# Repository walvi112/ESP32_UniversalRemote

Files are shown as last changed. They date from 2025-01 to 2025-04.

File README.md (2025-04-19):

# ESP32 Universal Remote  
A universal remote control powered by ESP32.

<p align="center">  
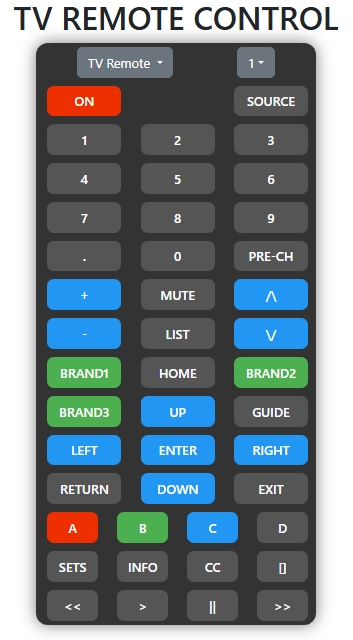
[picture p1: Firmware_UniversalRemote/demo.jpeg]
    
</p>

## Features

### 🔧 Hardware  
- IR receiver for learning new IR codes  
- 7 IR emitters for all-angle transmission

### 💻 Firmware  
- Web server to send/add new IR commands  
- mDNS service broadcasts the web server at [`remote.local`](http://remote.local)  
- Supports up to 5 different TV command sets  
- Supports up to 50 different IR protocols  
- Easy Wi-Fi setup via AP mode

---

## 🚀 Setup

### 📶 Wi-Fi Setup  
1. On startup, press the **user button** to enter AP mode  
2. Connect to the `esp32remote` Wi-Fi network  
3. In your browser, go to [`remote.local`](http://remote.local)  
4. Enter your Wi-Fi information and click `Submit`

<p align="center">  
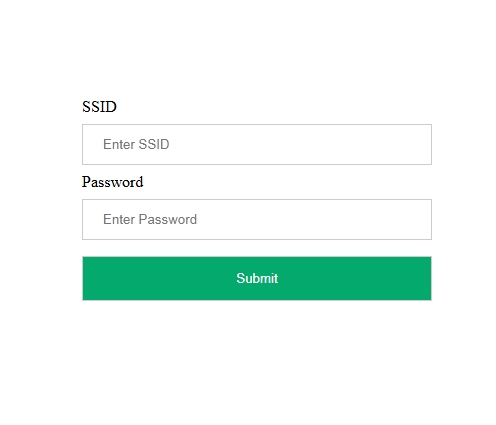
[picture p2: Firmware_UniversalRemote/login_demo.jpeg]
    
</p>

---

### 🔄 Send/Add IR Code

#### ➕ Add IR Code  
1. After setting the Wi-Fi network, go to [`remote.local`](http://remote.local)  
2. Select **Add TV** from the dropdown and choose a remote ID  
3. Click the **Register** button — the LED will start blinking  
4. Point your TV remote at the IR receiver and press a key  
5. If successful, the LED stops blinking; if not, it times out after 5 seconds

<p align="center">  
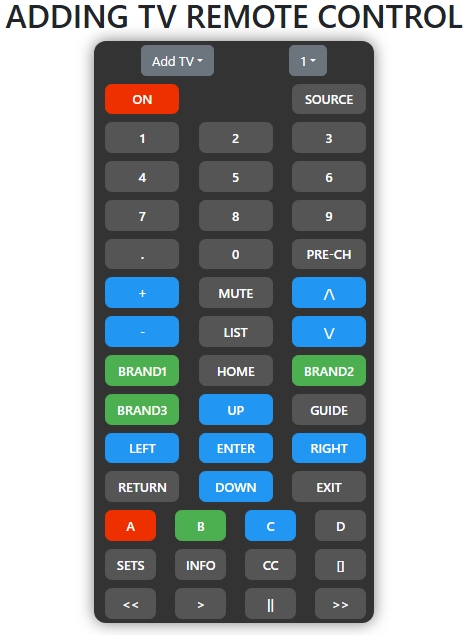
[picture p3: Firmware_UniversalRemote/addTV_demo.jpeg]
    
</p>

#### 📤 Send IR Code  
1. Select **TV Remote** and choose a remote ID from the dropdown  
2. Press the key you want to send

---

### 🐞 Debugging

- Use a serial monitor with **baud rate: 115200** to view logs  
- You can also send serial commands to the device

#### 🔧 Serial Commands  
| Command | Description |
|---|---|
| `led on` | Turn on the LED |
| `led off` | Turn off the LED |
| `send ir _protocol _address _command` | Send IR code (all values in decimal). Refer to `irmpprotocols.h` for `_protocol` values |
| `set wifi _ssid+_pwd` | Set Wi-Fi SSID and password |
| `add tv ir _ir_code _remote_id` | Add new IR command to `_remote_id`. LED will blink while waiting for input |
| `reset wifi` | Enter AP mode (same as pressing user button) |
| `restart` | Restart the device |

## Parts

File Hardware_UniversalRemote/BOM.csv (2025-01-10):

Reference | Value | Datasheet | Footprint | Qty | DNP
C1,C4,C8 | 0.1uF | ~ | Capacitor_THT:C_Disc_D3.4mm_W2.1mm_P2.50mm | 3
C2 | CP/10uF | ~ | Capacitor_THT:CP_Radial_D5.0mm_P2.00mm | 1
C3,C5 | 10uF | ~ | Capacitor_THT:CP_Radial_D4.0mm_P2.00mm | 2
C6 | CP/100uF | ~ | Capacitor_THT:CP_Radial_D8.0mm_P3.50mm | 1
C7 | CP/4.7uF | ~ | Capacitor_THT:CP_Radial_D5.0mm_P2.00mm | 1
C9,C10,C11 | 0.1uF/50V | ~ | Capacitor_THT:C_Disc_D3.4mm_W2.1mm_P2.50mm | 3
CB1 | 750mA/13.5V | ~ | Fuse:Fuse_1812_4532Metric_Pad1.30x3.40mm_HandSolder | 1
D1 | 5.1V/1W | ~ | Diode_THT:D_DO-41_SOD81_P7.62mm_Horizontal | 1
D2 | LED | ~ | LED_THT:LED_D3.0mm | 1
D3,D4,D5,D6,D7,D8,D9 | IR333-A | ~ | LED_THT:LED_D5.0mm | 7
J1 | USB_B_Micro | ~ | Connector_USB:USB_Micro-B_Wuerth_629105150521 | 1
Q1,Q3,Q4,Q5,Q6,Q7 | S8050 | http://www.unisonic.com.tw/datasheet/S8050.pdf | Package_TO_SOT_THT:TO-92_Inline | 6
Q2 | BSS138 | https://www.onsemi.com/pub/Collateral/BSS138-D.PDF | Package_TO_SOT_SMD:SOT-23 | 1
R1,R3,R5,R8,R10,R11,R16 | 10k | ~ | Resistor_THT:R_Axial_DIN0207_L6.3mm_D2.5mm_P7.62mm_Horizontal | 7
R2,R4,R9,R13,R15 | 1k | ~ | Resistor_THT:R_Axial_DIN0207_L6.3mm_D2.5mm_P7.62mm_Horizontal | 5
R6,R7,R12,R14,R17 | 5.6R | ~ | Resistor_THT:R_Axial_DIN0414_L11.9mm_D4.5mm_P15.24mm_Horizontal | 5
SW1,SW2,SW3 | SW_Push | ~ | Button_Switch_THT:SW_TH_Tactile_Omron_B3F-10xx | 3
TP1,TP2,TP3,TP4,TP5 | TestPoint | ~ | TestPoint:TestPoint_Pad_D2.5mm | 5
U1 | ESP32-WROOM-32U | https://www.espressif.com/sites/default/files/documentation/esp32-wroom-32d_esp32-wroom-32u_datasheet_en.pdf | RF_Module:ESP32-WROOM-32U | 1
U2 | LM1117T-3.3 | http://www.ti.com/lit/ds/symlink/lm1117.pdf | Package_TO_SOT_THT:TO-220-3_Horizontal_TabDown | 1
U3 | HS0038B |  | Package_TO_SOT_THT:TO-92_Inline_Wide | 1
U4 | CH340C | https://datasheet.lcsc.com/szlcsc/Jiangsu-Qin-Heng-CH340C_C84681.pdf | Package_SO:SOIC-16_3.9x9.9mm_P1.27mm | 1

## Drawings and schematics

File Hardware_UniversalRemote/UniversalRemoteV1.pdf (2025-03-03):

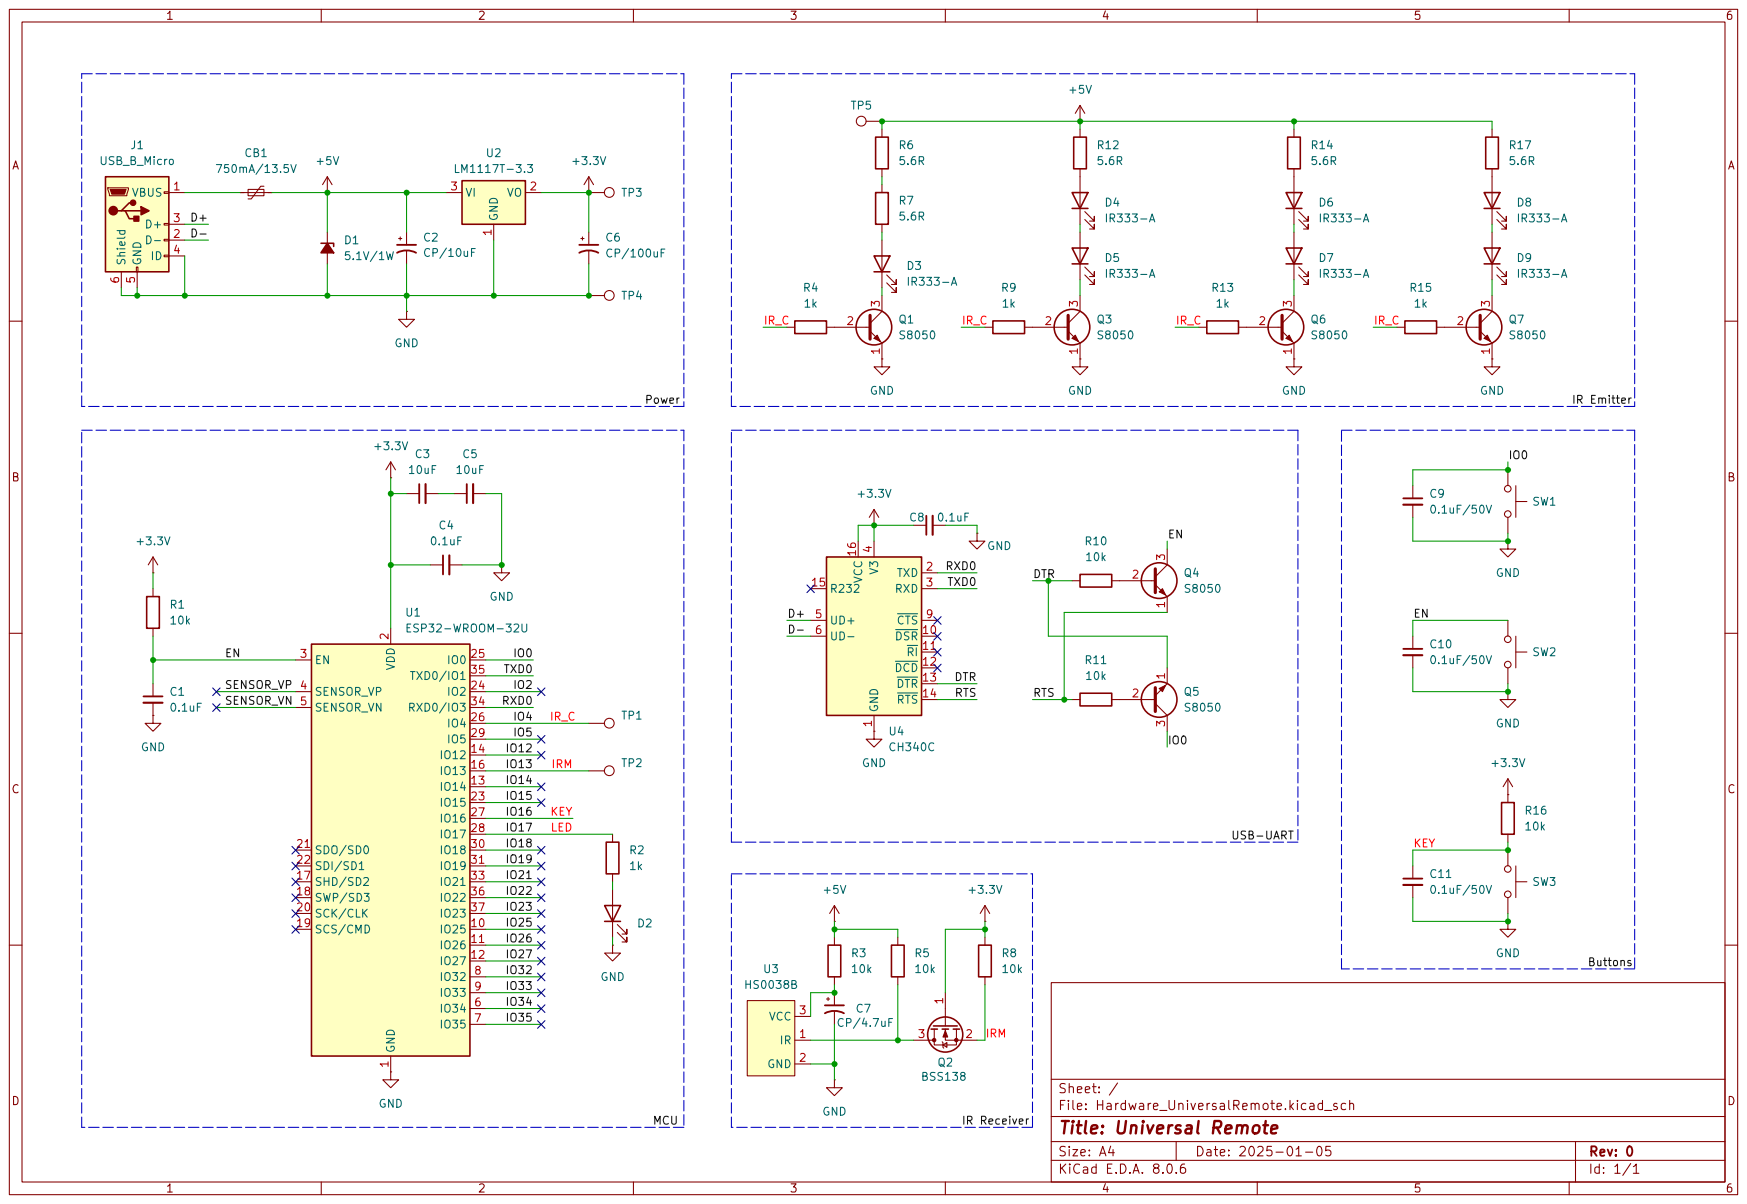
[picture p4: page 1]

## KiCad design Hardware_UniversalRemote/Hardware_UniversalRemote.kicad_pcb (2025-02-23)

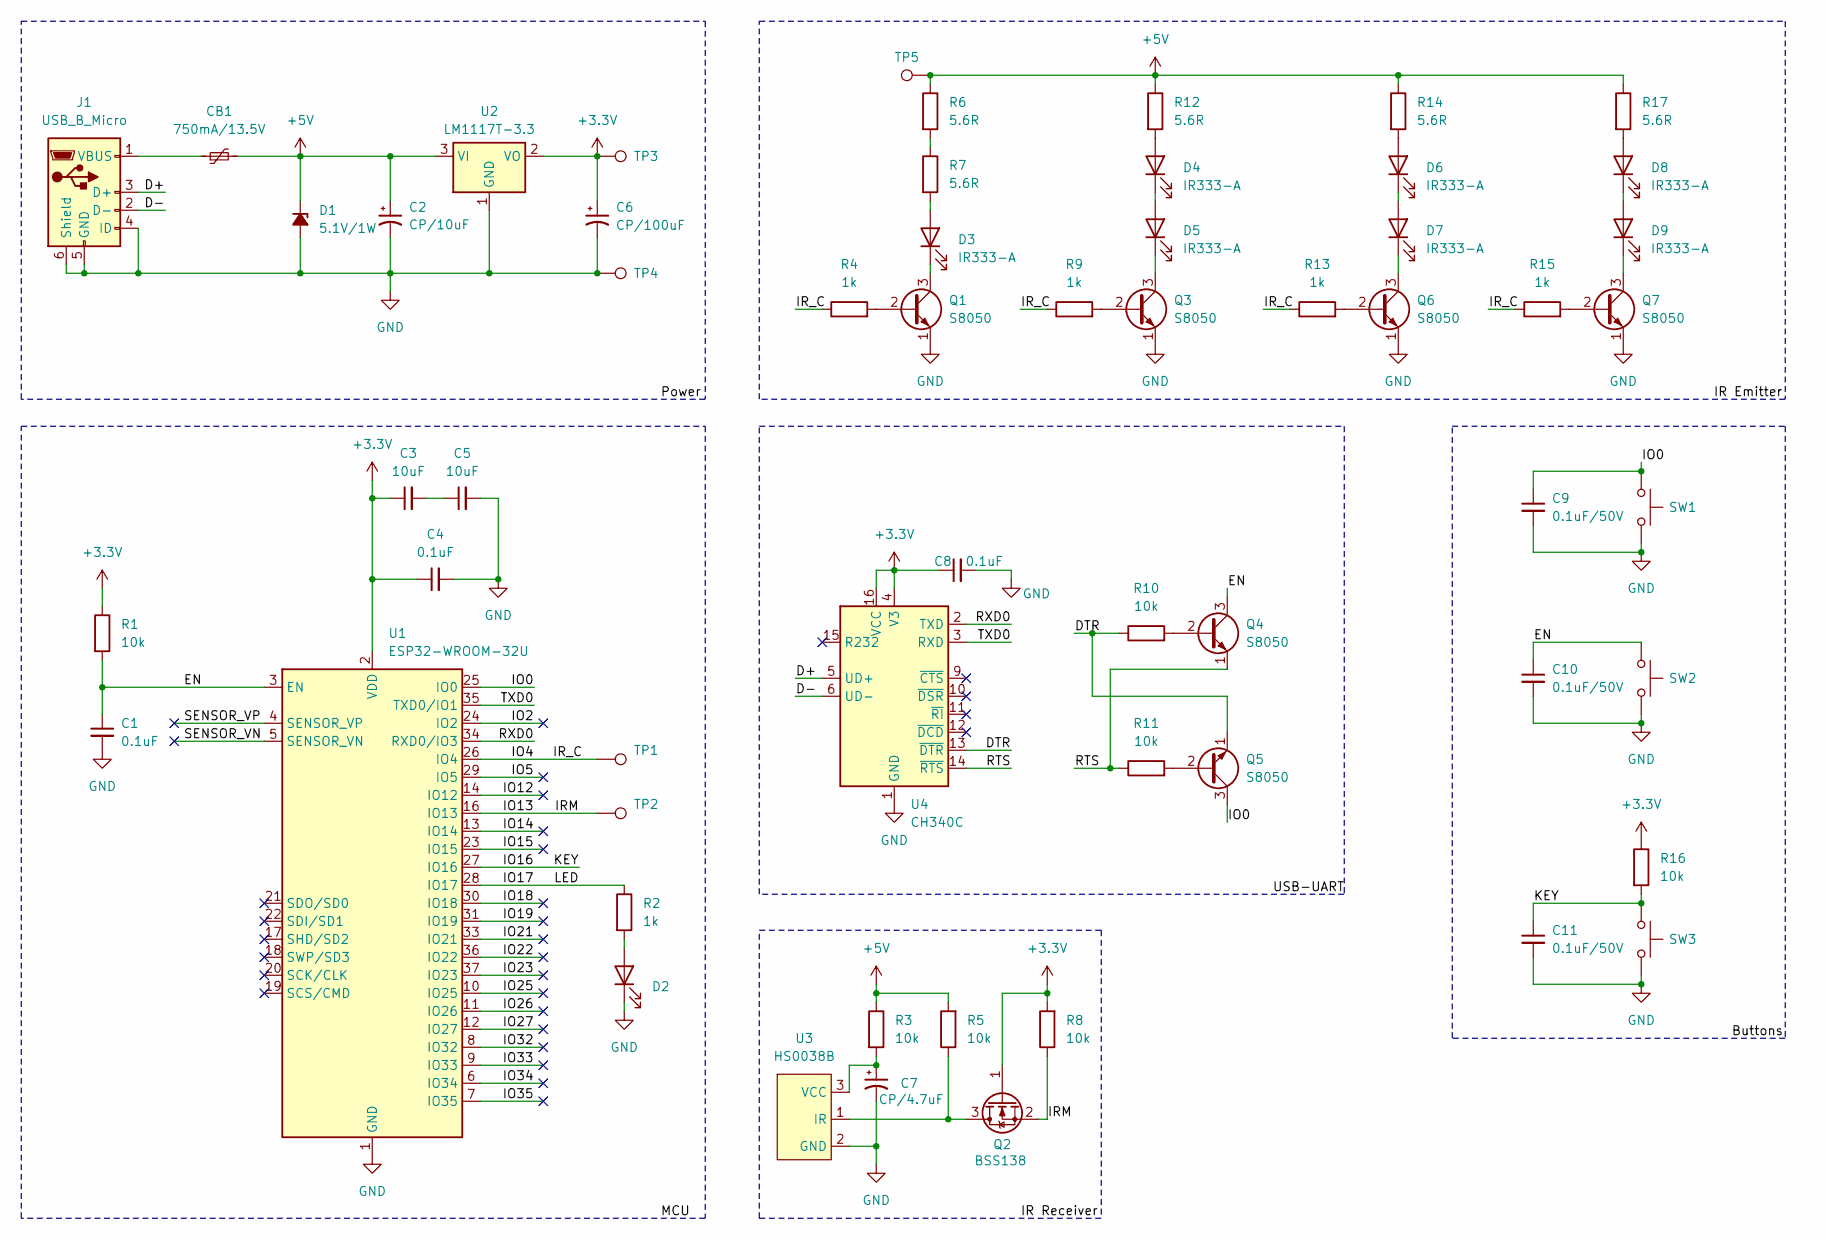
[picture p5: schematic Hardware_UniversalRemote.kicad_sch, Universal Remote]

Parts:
C1, C4, C8: 0.1uF; C_Disc_D3.4mm_W2.1mm_P2.50mm
C2: CP/10uF; CP_Radial_D5.0mm_P2.00mm
C3, C5: 10uF; CP_Radial_D4.0mm_P2.00mm
C6: CP/100uF; CP_Radial_D8.0mm_P3.50mm
C7: CP/4.7uF; CP_Radial_D5.0mm_P2.00mm
C9, C10, C11: 0.1uF/50V; C_Disc_D3.4mm_W2.1mm_P2.50mm
CB1: 750mA/13.5V; Fuse_1812_4532Metric_Pad1.30x3.40mm_HandSolder
D1: 5.1V/1W; D_DO-41_SOD81_P7.62mm_Horizontal
D2: LED; LED_D3.0mm
D3: IR333-A; LED_D5.0mm
D4, D5, D6, D7, D8, D9: IR333-A; LED_D5.0mm_Horizontal_O3.81mm_Z9.0mm
J1: USB_B_Micro; USB_Micro-B_Wuerth_629105150521
Q1, Q3, Q4, Q5, Q6, Q7: S8050; TO-92_Inline
Q2: BSS138; SOT-23
R1, R3, R5, R8, R10, R11, R16: 10k; R_Axial_DIN0207_L6.3mm_D2.5mm_P7.62mm_Horizontal
R2, R4, R9, R13, R15: 1k; R_Axial_DIN0207_L6.3mm_D2.5mm_P7.62mm_Horizontal
R6, R7, R12, R14, R17: 5.6R; R_Axial_DIN0414_L11.9mm_D4.5mm_P15.24mm_Horizontal
SW1, SW2, SW3: SW_Push; SW_TH_Tactile_Omron_B3F-10xx
TP1, TP2, TP3, TP4, TP5: TestPoint; TestPoint_Pad_D2.5mm
U1: ESP32-WROOM-32U
U2: LM1117T-3.3; TO-220-3_Horizontal_TabDown
U3: HS0038B; TO-92_Inline_Wide
U4: CH340C; SOIC-16_3.9x9.9mm_P1.27mm

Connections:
+3.3V: C3.1, C4.1, C6.1, C8.1, Q2.1 (G), R1.1, R8.2, R16.1, TP3.1, U1.2 (VDD), U2.2 (VO), U4.4 (V3), U4.16 (VCC)
+5V: C2.1, CB1.2, D1.1 (K), R3.1, R5.2, R6.1, R12.1, R14.1, R17.1, TP5.1, U2.3 (VI)
/D+: J1.3 (D+), U4.5 (UD+)
/D-: J1.2 (D-), U4.6 (UD-)
/DTR: Q5.1 (E), R10.1, U4.13 (~DTR)
/EN: C1.1, C10.1, Q4.3 (C), R1.2, SW2.1, U1.3 (EN)
/IO0: C9.1, Q5.3 (C), SW1.1, U1.25 (IO0)
/IO2: U1.24 (IO2)
/IO4: R4.1, R9.1, R13.1, R15.1, TP1.1, U1.26 (IO4)
/IO5: U1.29 (IO5)
/IO12: U1.14 (IO12)
/IO13: Q2.2 (S), R8.1, TP2.1, U1.16 (IO13)
/IO14: U1.13 (IO14)
/IO15: U1.23 (IO15)
/IO16: C11.1, R16.2, SW3.1, U1.27 (IO16)
/IO17: R2.1, U1.28 (IO17)
/IO18: U1.30 (IO18)
/IO19: U1.31 (IO19)
/IO21: U1.33 (IO21)
/IO22: U1.36 (IO22)
/IO23: U1.37 (IO23)
/IO25: U1.10 (IO25)
/IO26: U1.11 (IO26)
/IO27: U1.12 (IO27)
/IO32: U1.8 (IO32)
/IO33: U1.9 (IO33)
/IO34: U1.6 (IO34)
/IO35: U1.7 (IO35)
/RTS: Q4.1 (E), R11.1, U4.14 (~RTS)
/RXD0: U1.34 (RXD0/IO3), U4.2 (TXD)
/SENSOR_VN: U1.5 (SENSOR_VN)
/SENSOR_VP: U1.4 (SENSOR_VP)
/TXD0: U1.35 (TXD0/IO1), U4.3 (RXD)
GND: C1.2, C2.2, C4.2, C5.2, C6.2, C7.2, C8.2, C9.2, C10.2, C11.2, D1.2 (A), D2.1 (K), J1.4 (ID), J1.5 (GND), J1.6 (Shield), Q1.1 (E), Q3.1 (E), Q6.1 (E), Q7.1 (E), SW1.2, SW2.2, SW3.2, TP4.1, U1.1 (GND), U1.15 (GND), U1.38 (GND), U1.39 (GND), U2.1 (GND), U3.2 (GND), U4.1 (GND)
unnamed: C3.2, C5.1
unnamed: D2.2 (A), R2.2
unnamed: D3.2 (A), R7.2
unnamed: D3.1 (K), Q1.3 (C)
unnamed: D4.2 (A), R12.2
unnamed: D4.1 (K), D5.2 (A)
unnamed: D5.1 (K), Q3.3 (C)
unnamed: D6.2 (A), R14.2
unnamed: D6.1 (K), D7.2 (A)
unnamed: D7.1 (K), Q6.3 (C)
unnamed: D8.2 (A), R17.2
unnamed: D8.1 (K), D9.2 (A)
unnamed: D9.1 (K), Q7.3 (C)
unnamed: CB1.1, J1.1 (VBUS)
unnamed: Q1.2 (B), R4.2
unnamed: Q2.3 (D), R5.1, U3.1 (IR)
unnamed: Q3.2 (B), R9.2
unnamed: Q4.2 (B), R10.2
unnamed: Q5.2 (B), R11.2
unnamed: Q6.2 (B), R13.2
unnamed: Q7.2 (B), R15.2
unnamed: R6.2, R7.1
unnamed: C7.1, R3.2, U3.3 (VCC)

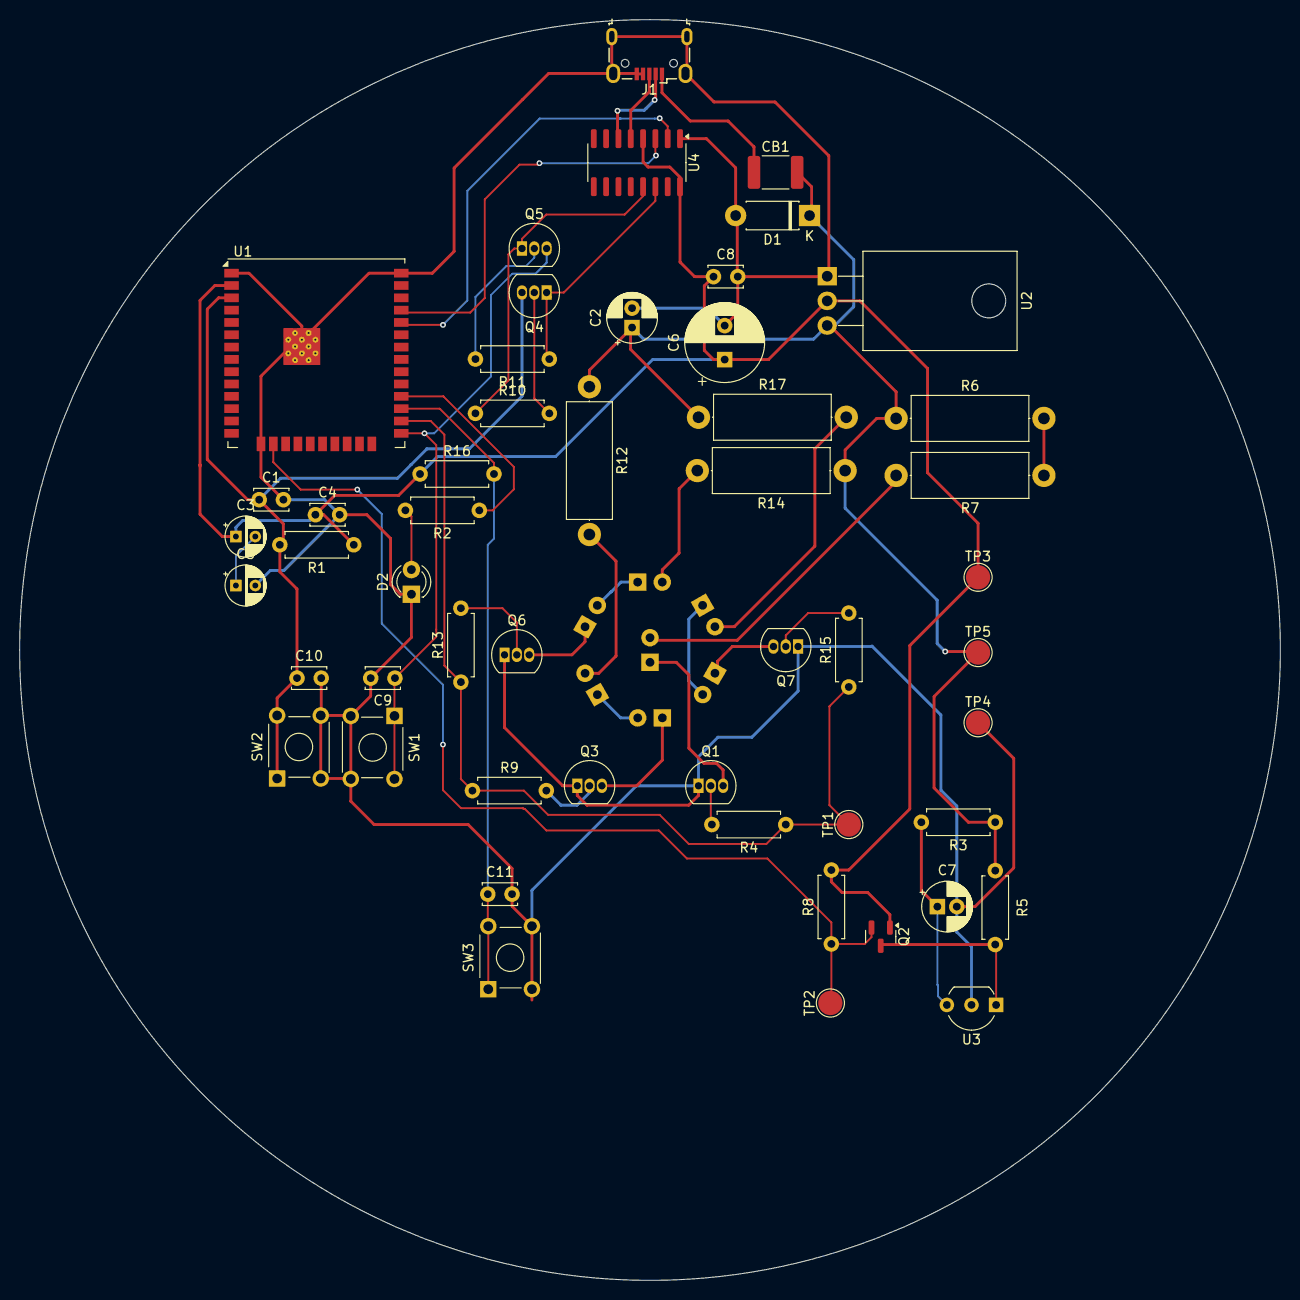
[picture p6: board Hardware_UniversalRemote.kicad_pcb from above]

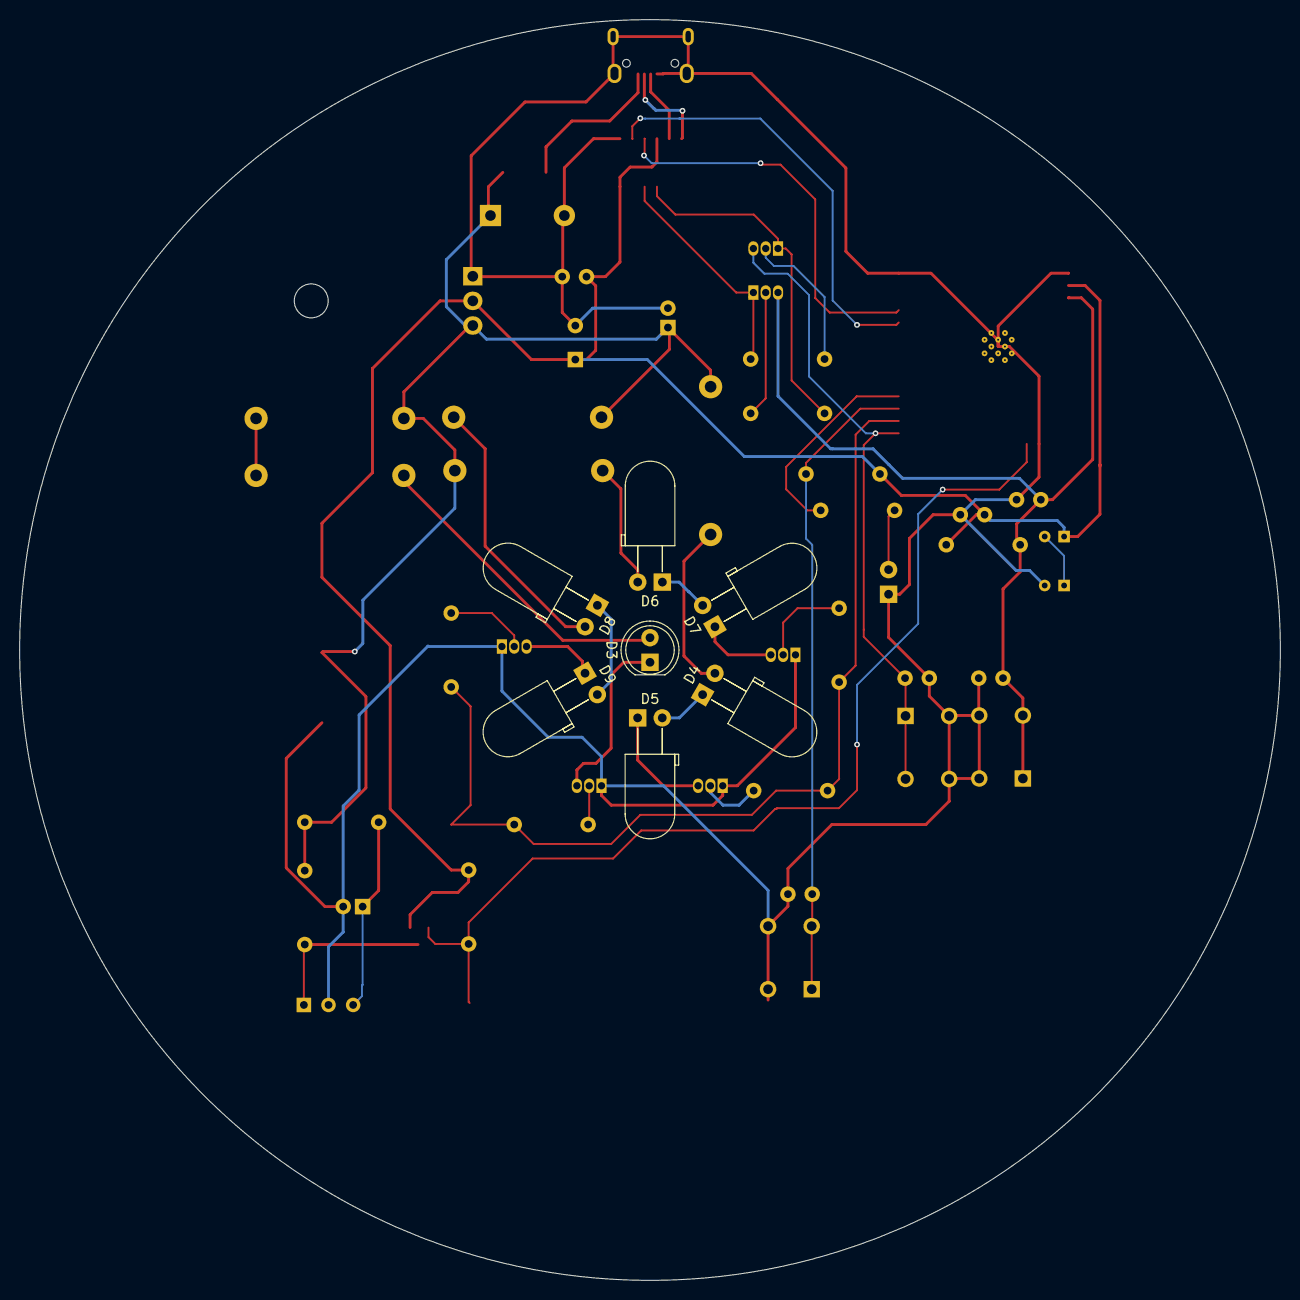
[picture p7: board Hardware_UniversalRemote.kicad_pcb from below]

Board: 2 copper layers, 130.0 x 130.0 mm, 58 parts (7 on the bottom side), 38 nets.

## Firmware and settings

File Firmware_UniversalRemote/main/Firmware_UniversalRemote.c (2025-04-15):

#include <stdio.h>
#include <stdint.h>
#include "freertos/FreeRTOS.h"
#include "freertos/task.h"
#include "driver/gpio.h"
#include "driver/uart.h"
#include "nvs_flash.h"
#include "esp_system.h"
#include "wifi_connect.h"
#include "webserver.h"
#include "ir_manage.h"
#include "pin_config.h"

#define UART_BUFFER_SIZE     2048

TaskHandle_t key_press_task_handle;
char uart_buffer[UART_BUFFER_SIZE];

void cli_task(void *args);
void key_press_task(void *args);

static void IRAM_ATTR key_isr_handler(void *args)
{
    BaseType_t xHigherPriorityTaskWoken;
    vTaskNotifyGiveFromISR(key_press_task_handle, &xHigherPriorityTaskWoken);
    if (xHigherPriorityTaskWoken) {
        portYIELD_FROM_ISR();
    }
}

void app_main(void)
{   
    esp_err_t ret = nvs_flash_init();
    if (ret == ESP_ERR_NVS_NO_FREE_PAGES || ret == ESP_ERR_NVS_NEW_VERSION_FOUND) {
        ESP_ERROR_CHECK(nvs_flash_erase());
        ret = nvs_flash_init();
    }
    ESP_ERROR_CHECK(ret);

    const uart_port_t uart_num = UART_NUM_0;
    uart_config_t uart_config = {
        .baud_rate = 115200,
        .data_bits = UART_DATA_8_BITS,
        .parity = UART_PARITY_DISABLE,
        .stop_bits = UART_STOP_BITS_1,
        .flow_ctrl = UART_HW_FLOWCTRL_DISABLE,
    };
    ESP_ERROR_CHECK(uart_param_config(uart_num, &uart_config));
    ESP_ERROR_CHECK(uart_set_pin(uart_num, GPIO_NUM_1, GPIO_NUM_3, UART_PIN_NO_CHANGE, UART_PIN_NO_CHANGE));
    ESP_ERROR_CHECK(uart_driver_install(uart_num, UART_BUFFER_SIZE, 0, 0, NULL, 0));

    gpio_reset_pin(LED_PIN);
    gpio_set_direction(LED_PIN, GPIO_MODE_OUTPUT);
    gpio_set_level(LED_PIN, 1);

    gpio_reset_pin(KEY_PIN);
    gpio_set_direction(KEY_PIN, GPIO_MODE_INPUT);
    gpio_set_pull_mode(KEY_PIN, GPIO_FLOATING);
    gpio_set_intr_type(KEY_PIN, GPIO_INTR_NEGEDGE);

    gpio_install_isr_service(ESP_INTR_FLAG_IRAM);
    gpio_isr_handler_add(KEY_PIN, key_isr_handler, (void*) KEY_PIN);
    gpio_dump_io_configuration(stdout, (1ULL << LED_PIN) | (1ULL << KEY_PIN));

    ESP_ERROR_CHECK(ir_init());
    ESP_ERROR_CHECK(ir_storage_init());
    ESP_ERROR_CHECK(wifi_init());
    ESP_ERROR_CHECK(startwebserver());

    xTaskCreatePinnedToCore(&cli_task, "CLI_TASK", 4096, NULL, 1, NULL, 1);
    xTaskCreatePinnedToCore(&key_press_task, "KEY_PRESS_TASK", 2048, NULL, 2, &key_press_task_handle, 1);
}

esp_err_t str_to_parram_int(char *input, int *output_array, unsigned int array_length)
{
    uint8_t token_count = 0;
    char *pch = strtok(input, " ");
    while (pch != NULL && token_count < array_length) {
        output_array[token_count] = strtol(pch, NULL, 10);
        pch = strtok(NULL, " ");
        token_count += 1;    
    }
    if (token_count < array_length) {
        return ESP_FAIL;
    }
    return ESP_OK;
}

esp_err_t str_to_parram_str(char *input, char **output_array, unsigned int array_length)
{
    uint8_t token_count = 0;
    char *pch = strtok(input, "+");
    while (pch != NULL && token_count < array_length) {
        printf("%s\n", pch);
        output_array[token_count] = pch;
        pch = strtok(NULL, "+");
        token_count += 1;
    }
    if (token_count < array_length) {
        return ESP_FAIL;
    }
    return ESP_OK;
}

void key_press_task(void *args)
{
    TickType_t now_tick = 0;
    TickType_t previous_tick = 0;
    while (1)
    {
        ulTaskNotifyTake(pdTRUE, portMAX_DELAY);
        now_tick = xTaskGetTickCount();
        if ((now_tick - previous_tick) >= (DEBOUNCE_PERIOD_MS / portTICK_PERIOD_MS)) {
            previous_tick = now_tick;
            printf("User key pressed\n");
            reset_wifi();
        }
    }
}

void cli_task(void *args)
{
    int length = 0;
    while (1)
    {
        length = uart_read_bytes(UART_NUM_0, uart_buffer, UART_BUFFER_SIZE - 1, 20 / portTICK_PERIOD_MS);
        if (length) {
            uart_buffer[length] = '\0';
            uart_write_bytes(UART_NUM_0, uart_buffer, length);
            // led on : turn on indicator led
            if (strncmp(uart_buffer, "led on", strlen("led on")) == 0) {
                printf(">Led on\n");
                gpio_set_level(LED_PIN, 1);
            }
            // led off : turn off indicator led
            else if (strncmp(uart_buffer, "led off", strlen("led off")) == 0) {
                printf(">Led off\n");
                gpio_set_level(LED_PIN, 0);
            }
            // send ir protocol+address+command : send ir code
            else if (strncmp(uart_buffer, "send ir ", strlen("send ir ")) == 0) {
                int ir_send[3];
                if (str_to_parram_int(uart_buffer + strlen("send ir "), ir_send, 3) == ESP_FAIL) {
                    continue;
                }
                if (xSemaphoreTake(ir_mutex, 10 / portTICK_PERIOD_MS) == pdTRUE) {
                    printf(">Sent IR: %d %d %d\n", ir_send[0], ir_send[1], ir_send[2]);
                    irmp_data.address  = (uint16_t) ir_send[1];       
                    irmp_data.command  = (uint16_t) ir_send[2];       
                    irmp_data.flags    = 0;
                    irmp_data.protocol = (uint8_t) ir_send[0];
                    irsnd_send_data (&irmp_data, TRUE);
                    xSemaphoreGive(ir_mutex);
                }
            }
            // set wifi ssid+pwd : set wifi 
            else if (strncmp(uart_buffer, "set wifi ", strlen("set wifi ")) == 0) {
                char *wifi_new[2];
                if(str_to_parram_str(uart_buffer + strlen("set wifi "), wifi_new, 2) == ESP_FAIL) {
                    printf(">Format should be: set wifi ssid+pwd.\n");
                    continue;
                }
                char *ptr;
                ptr = strrchr(wifi_new[1], '\r');
                if (ptr != NULL) {
                    *ptr = '\0';
                }
                ptr = strrchr(wifi_new[1], '\n');
                if (ptr != NULL) {
                    *ptr = '\0';
                }
                if (strlen(wifi_new[0]) >= MAX_WIFI_SSID_LENGTH || strlen(wifi_new[1]) >= MAX_WIFI_PWD_LENGTH) {
                    printf(">SSID or PWD to long.\n");    
                }
                else {
                    printf(">Set WIFI SSID: %s\n", wifi_new[0]);
                    set_wifi(wifi_new[0], wifi_new[1]);
                }
            }
            // add tv ir ir_code remote_id : enter add tv ir mode
            else if (strncmp(uart_buffer, "add tv ir ", strlen("add tv ir ")) == 0) {
                int ir_receive[2];
                if (str_to_parram_int(uart_buffer + strlen("add tv ir "), ir_receive, 2) == ESP_FAIL) {
                    continue;
                }
                printf(">Add TV IR, please point the TV remote to the receiver and press key.\n");
                ir_add_code_tv_detect(ir_receive[0], ir_receive[1]);
            } 
            // restart : restart device
            else if (strncmp(uart_buffer, "restart", strlen("restart")) == 0) {
                printf(">Restart device.\n");
                esp_restart();
            }
            else if (strncmp(uart_buffer, "reset wifi", strlen("reset wifi")) == 0) {
                printf(">Reset wifi.\n");
                reset_wifi();
            }
        }
    }    
}

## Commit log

2025-01-06 add power block
    [Hardware_UniversalRemote.kicad_sch]
2025-01-06 add IR emitter block
    [Hardware_UniversalRemote.kicad_sch]
2025-01-07 add mcu
    [Hardware_UniversalRemote.kicad_sch]
2025-01-07 add buttons and usb-uart block
    [Hardware_UniversalRemote.kicad_sch]
2025-01-08 add mcu and ir receiver block
    [Hardware_UniversalRemote.kicad_sch]
2025-01-08 add capacitor footprint
    [Hardware_UniversalRemote.kicad_sch]
2025-01-09 add net list
    [BOM.csv, Hardware_UniversalRemote.kicad_sch]
2025-01-09 fix regulator voltage
    [Hardware_UniversalRemote.kicad_pcb]
2025-01-10 add first pcb layout
    [BOM.csv, Hardware_UniversalRemote.kicad_pcb, Hardware_UniversalRemote.kicad_sch]
2025-01-12 add first pcb layout version
    [Hardware_UniversalRemote.kicad_pcb, Hardware_UniversalRemote.kicad_sch]
2025-01-13 improve layout
    [Hardware_UniversalRemote.kicad_pcb]
2025-01-14 modify layout
    [Hardware_UniversalRemote.kicad_pcb, Hardware_UniversalRemote.kicad_sch]
2025-01-14 modify routing
    [Hardware_UniversalRemote.kicad_pcb, Hardware_UniversalRemote.kicad_sch]
2025-01-15 add trace
    [Hardware_UniversalRemote.kicad_pcb, Hardware_UniversalRemote.kicad_sch]
2025-01-15 finished second pcb layout
    [Hardware_UniversalRemote.kicad_pcb]
2025-01-29 add pdf for schematic v1
2025-02-23 fix txd/rxd routing for mcu flashing
    [Hardware_UniversalRemote.kicad_pcb, Hardware_UniversalRemote.kicad_sch]
2025-03-03 fix alignment
    [Hardware_UniversalRemote.kicad_sch]
2025-03-09 switch to wifi sta mode and add favicon
2025-03-11 fix bug function str_to_parram_int
    [Firmware_UniversalRemote.c]
2025-03-19 fix wrong wifi ssid input length
    [Firmware_UniversalRemote.c]
2025-04-11 fix bug device reset when change wifi parameter
2025-04-12 fix stick hover button when displaying on webkit
